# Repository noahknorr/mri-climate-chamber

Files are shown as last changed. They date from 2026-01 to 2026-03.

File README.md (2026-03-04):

# mri-climate-chamber
This is the repository for our open-source climate chamber with in-bore extension for plant MRI.
STEP files with the overall design, including the 3d-printed parts, as well as the layout for the custom PCBs can be downloaded and used according to the licence agreements. 
A technical description, Bill of Materials, performance characterization, and some exemplary measurments on plants can be found in the corresponding publication found under: 

(link not yet available)

We hope to lower the entry barrier to functional MR imaging of plants for other researchers.

# Licenses

All software is licensed under the terms of the GPL-3.0 license and may be used, modified, and redistributed freely, provided that the source code and any derivative works are distributed under the same license.

All hardware is licensed under the terms of the CERN-OHL-W v2 license and may be used, modified, and redistribute freely, provided that any distributed modifications remain under the same license and the source documentation is made available.

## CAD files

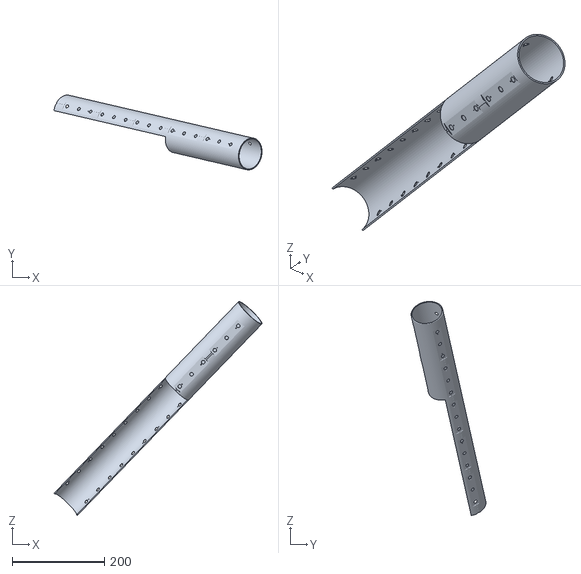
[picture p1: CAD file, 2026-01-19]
3d-files/STLs/einsatz_grundrohr_1.stl
451.2 x 162.3 x 464.4

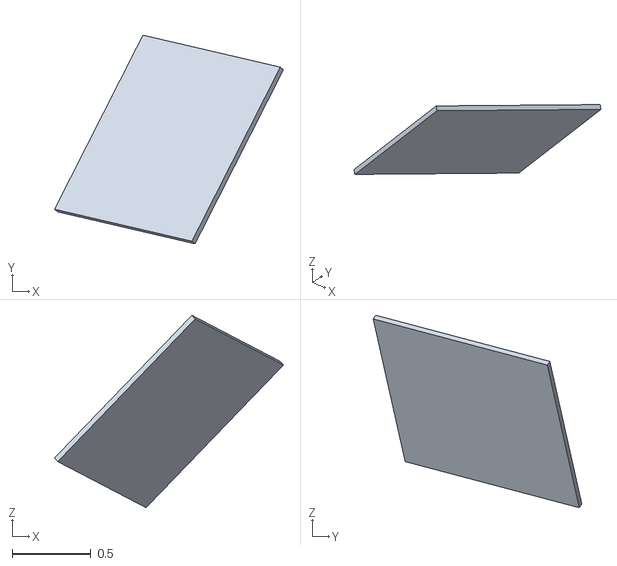
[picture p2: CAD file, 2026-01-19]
3d-files/STLs/einsatz_1_4_6.stl
1.45 x 1.32 x 1.22

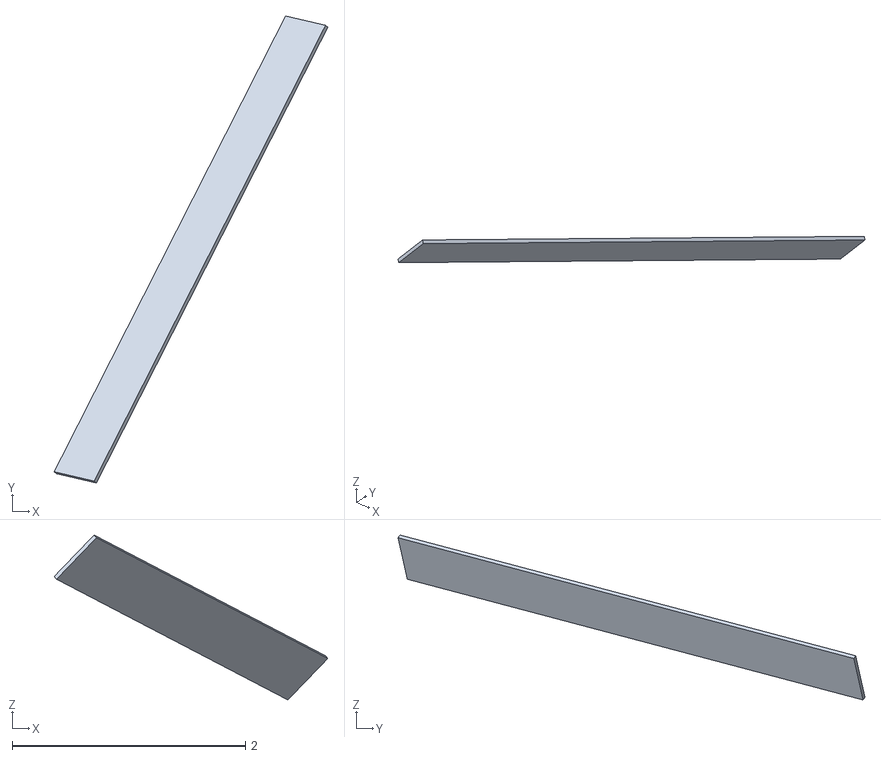
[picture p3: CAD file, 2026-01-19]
3d-files/STLs/einsatz_A_1_13.stl
2.35 x 4.00 x 1.41

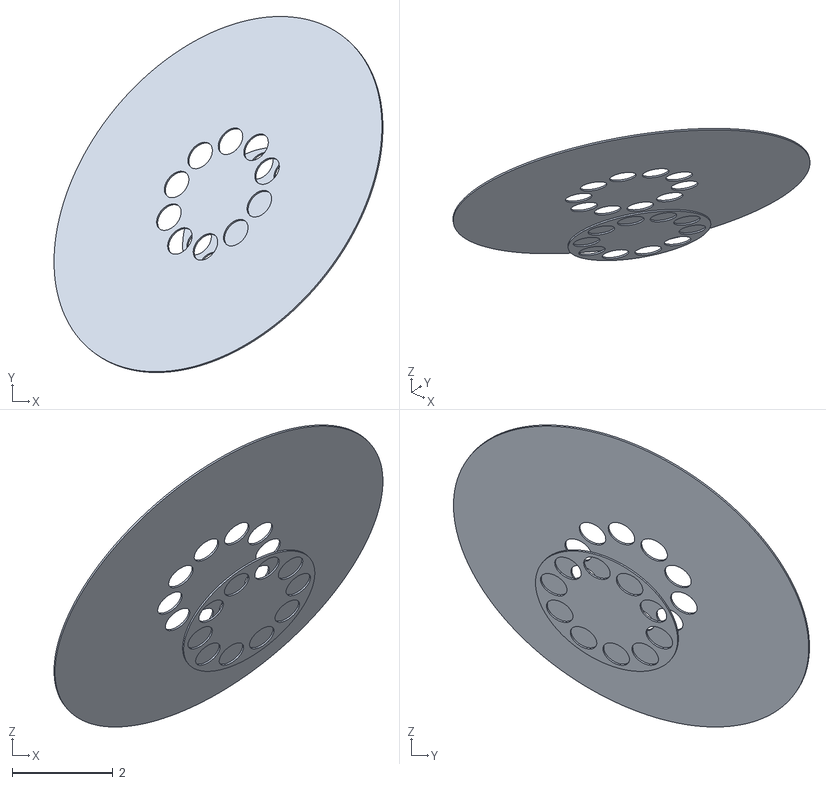
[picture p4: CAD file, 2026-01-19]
3d-files/STLs/einsatz_PIN_1_23.stl
6.53 x 7.07 x 6.00

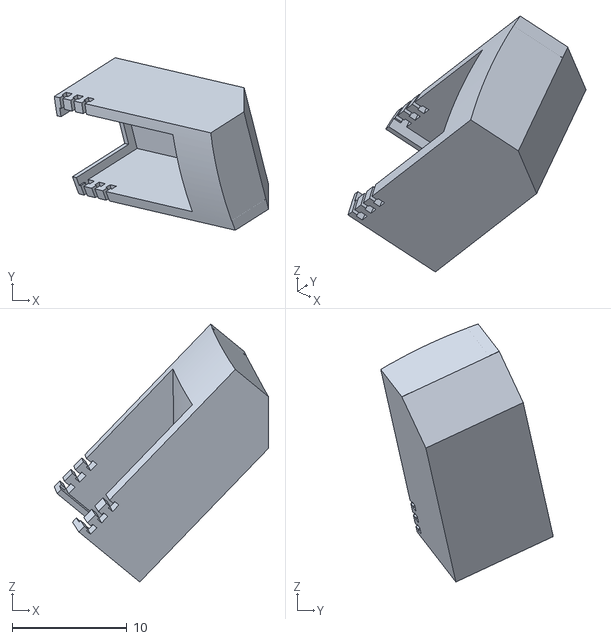
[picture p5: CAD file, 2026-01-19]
3d-files/STLs/einsatz_steckergehaeuseMitAusschnitt_44.stl
18.7 x 15.0 x 22.5

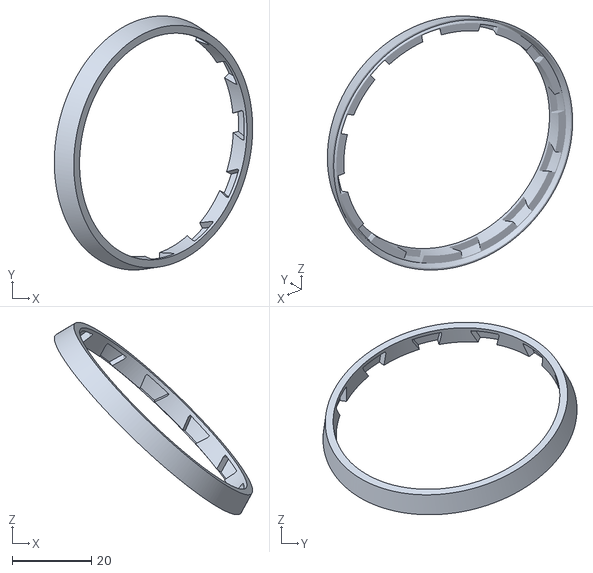
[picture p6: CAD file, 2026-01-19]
3d-files/STLs/einsatz_aufsatzStatorGummi_52.stl
50.1 x 64.2 x 48.6

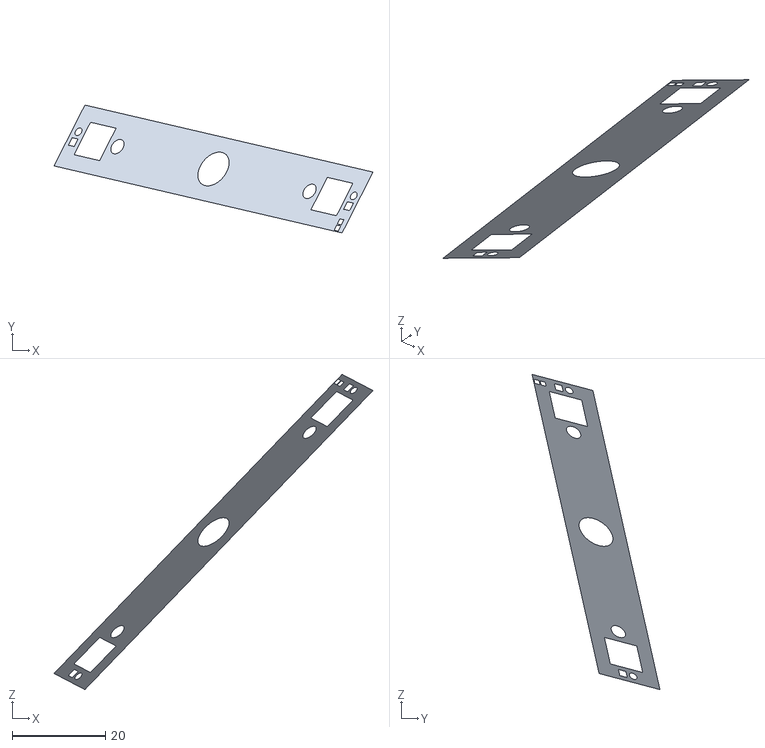
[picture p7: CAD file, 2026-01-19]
3d-files/STLs/einsatz_SOLDERMASK_BOTTOM_34.stl
68.3 x 27.4 x 67.4

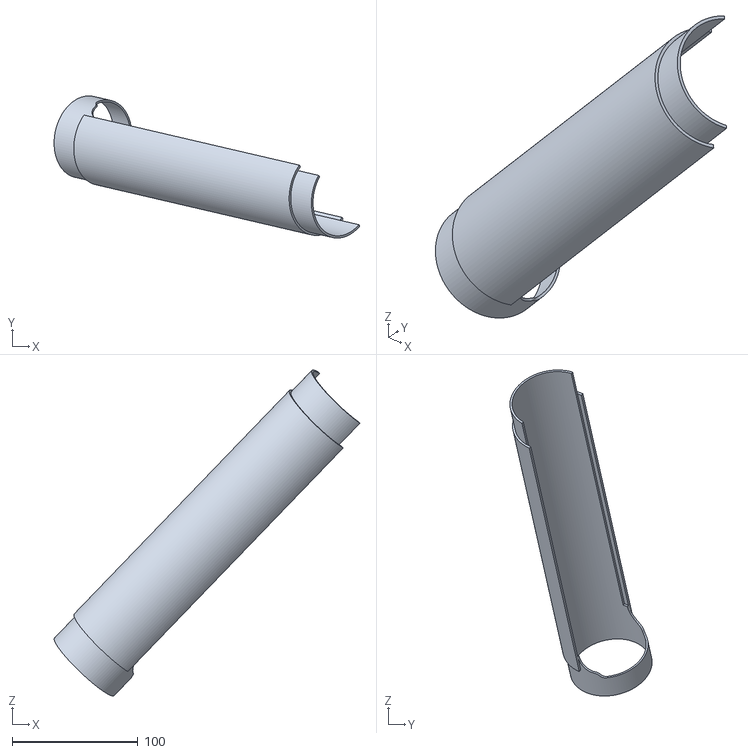
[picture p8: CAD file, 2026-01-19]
3d-files/STLs/einsatz_gegeneinsatz_56.stl
243.1 x 113.0 x 259.2

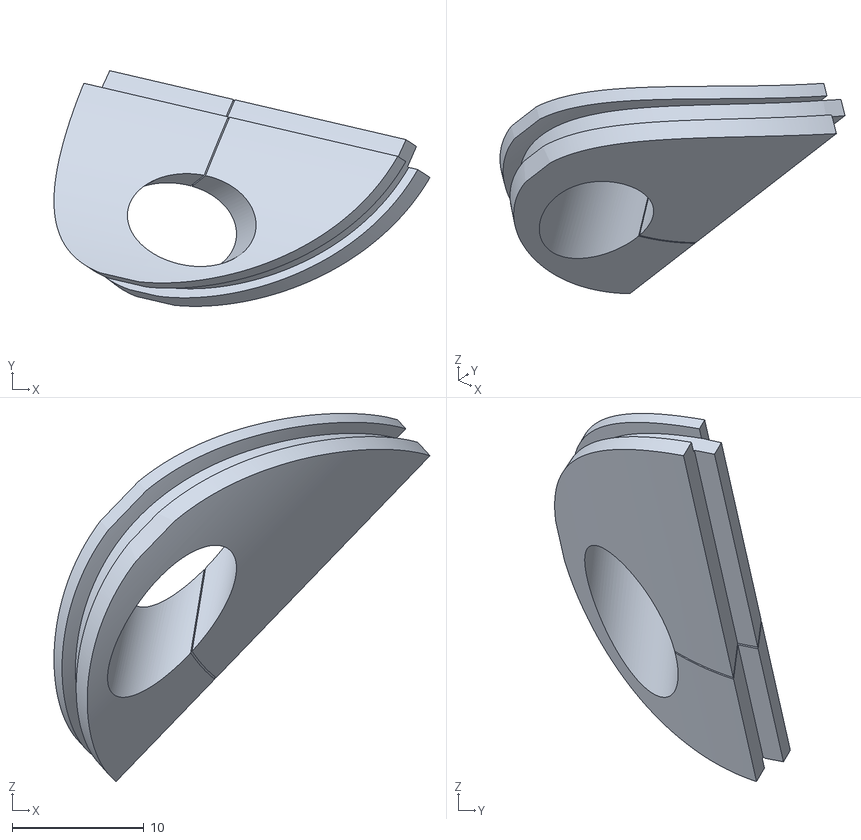
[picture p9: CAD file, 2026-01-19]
3d-files/STLs/einsatz_kappeU5mm_55.stl
28.6 x 17.9 x 28.0

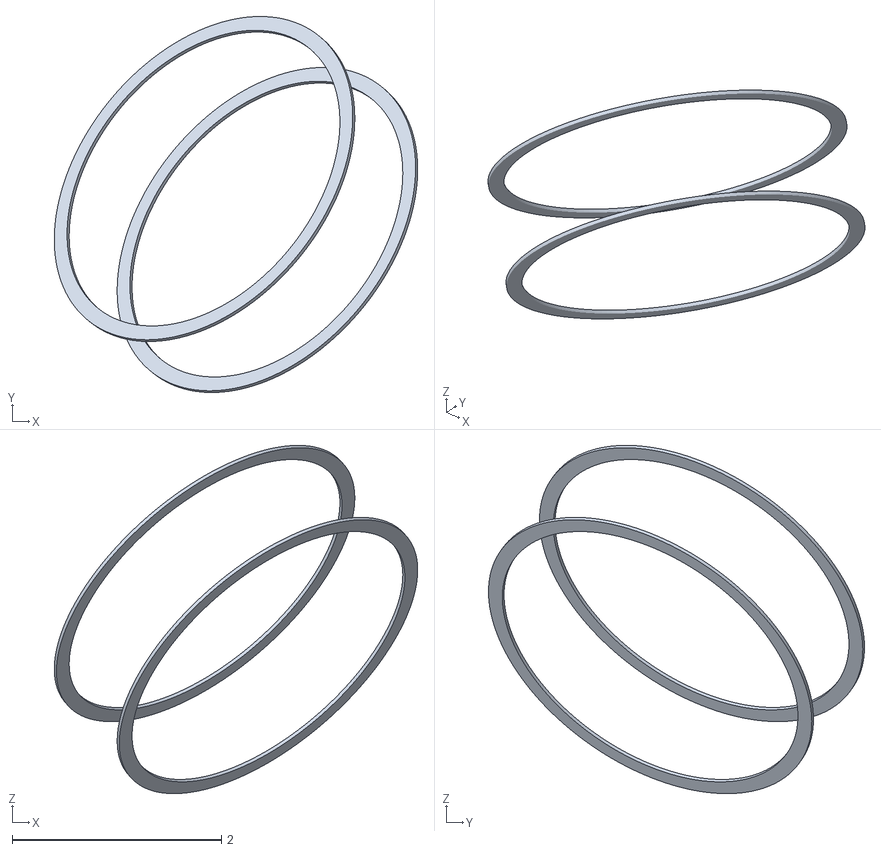
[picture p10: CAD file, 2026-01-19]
3d-files/STLs/einsatz_MECHANICAL PIN_20.stl
3.47 x 3.59 x 3.33

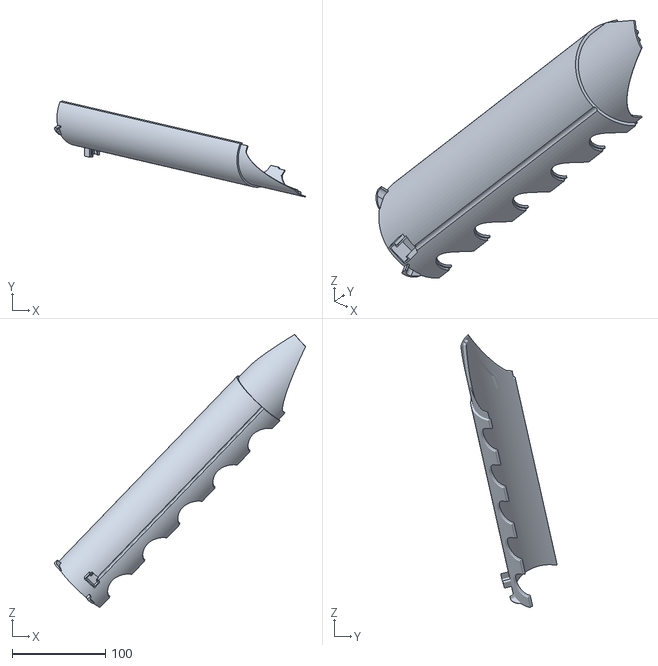
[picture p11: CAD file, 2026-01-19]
3d-files/STLs/einsatz_einsatzU_49.stl
269.7 x 103.3 x 293.1

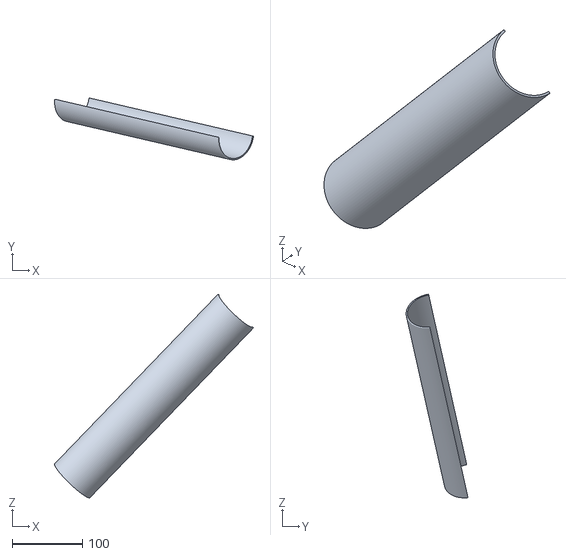
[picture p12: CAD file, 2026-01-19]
3d-files/STLs/einsatz_deckel_43.stl
284.2 x 88.2 x 291.0

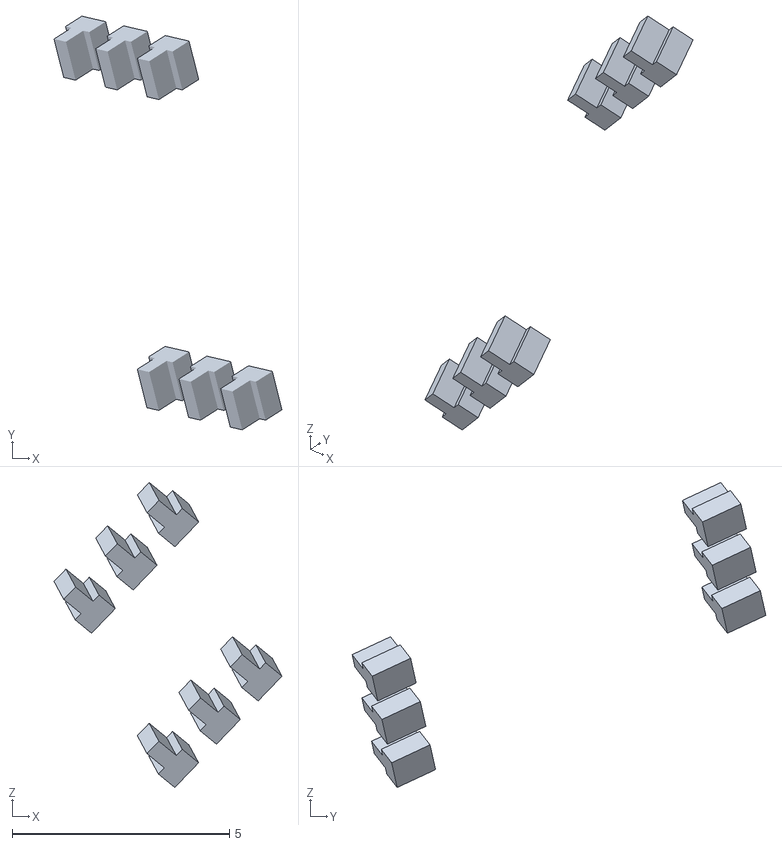
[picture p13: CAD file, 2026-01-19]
3d-files/STLs/einsatz_verbinderGrundrohrLaschen_45.stl
5.24 x 9.52 x 7.02

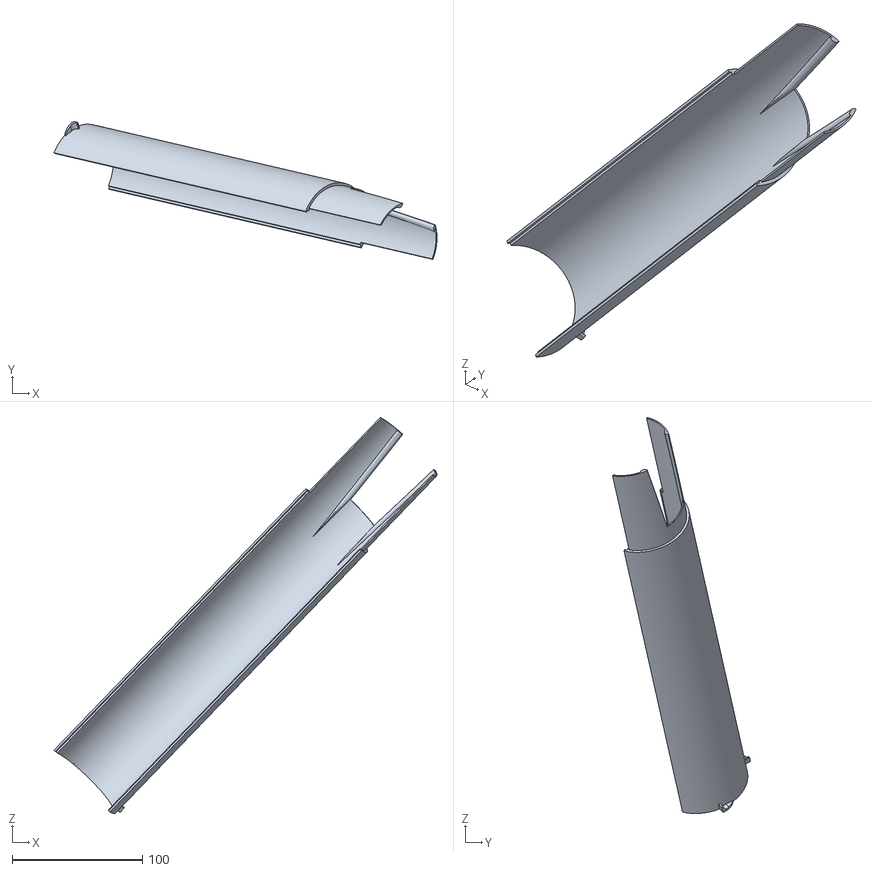
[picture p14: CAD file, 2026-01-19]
3d-files/STLs/einsatz_einsatzO_50.stl
294.1 x 105.9 x 304.2

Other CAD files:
3d-files/STLs/einsatz_steckergehaeuseMitAusschnitt_46.stl
3d-files/STLs/einsatz_MECHANICAL PIN_1_21.stl
3d-files/STLs/schlauchverbinderSchnellverschluss_verbinderHochflexibel-PVC_6.stl
3d-files/STLs/einsatz_SILKSCREEN_BOTTOM_36.stl
3d-files/STLs/einsatz_1_1_3.stl
3d-files/STLs/einsatz_1_2.stl
3d-files/STLs/einsatz_1_2_4.stl
3d-files/STLs/einsatz_1_3_5.stl
3d-files/STLs/einsatz_2_1_8.stl
3d-files/STLs/einsatz_2_2_9.stl
3d-files/STLs/einsatz_2_3_10.stl
3d-files/STLs/einsatz_2_4_11.stl
3d-files/STLs/einsatz_2_7.stl
3d-files/STLs/einsatz_A1_14.stl
3d-files/STLs/einsatz_A2_15.stl
3d-files/STLs/einsatz_A_12.stl
3d-files/STLs/einsatz_BOTTOM_33.stl
3d-files/STLs/einsatz_Dielectric_32.stl
3d-files/STLs/einsatz_HL2X_1_38.stl
3d-files/STLs/einsatz_HL2X_37.stl
3d-files/STLs/einsatz_K1_18.stl
3d-files/STLs/einsatz_K2_19.stl
3d-files/STLs/einsatz_K_16.stl
3d-files/STLs/einsatz_K_1_17.stl
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

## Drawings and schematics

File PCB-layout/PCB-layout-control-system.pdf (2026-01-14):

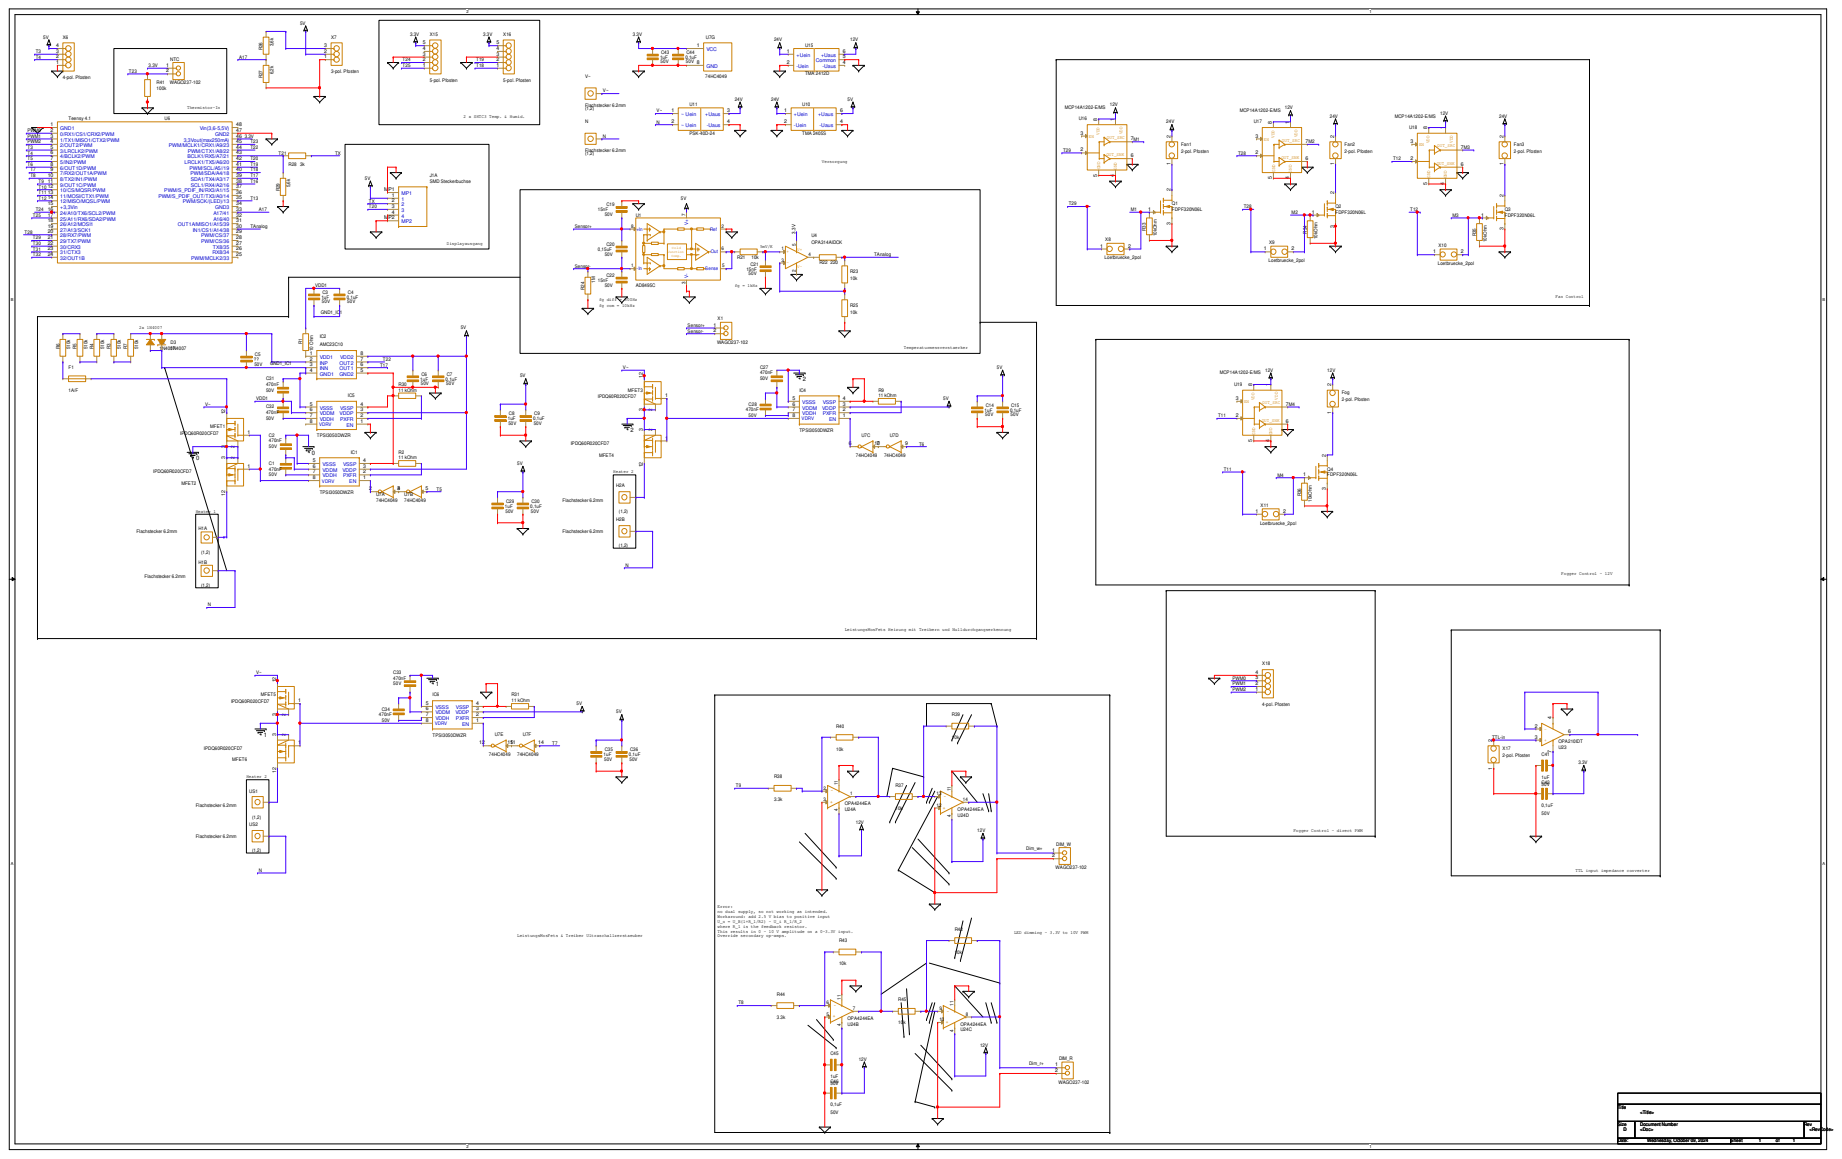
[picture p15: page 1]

LeistungsMosFets Heizung mit Treibern und Nulldurchgangserkennung

Fogger Control - direct PWM

TTL input impedance converter

Error:
no dual supply, so not working as intended.
Workaround: add 2.5 V bias to positive input
where R_1 is the feedback resistor.
This results in 0 - 10 V amplitude on a 0-3.3V input.
Override secondary op-amps.

LED dimming - 3.3V to 10V PWM

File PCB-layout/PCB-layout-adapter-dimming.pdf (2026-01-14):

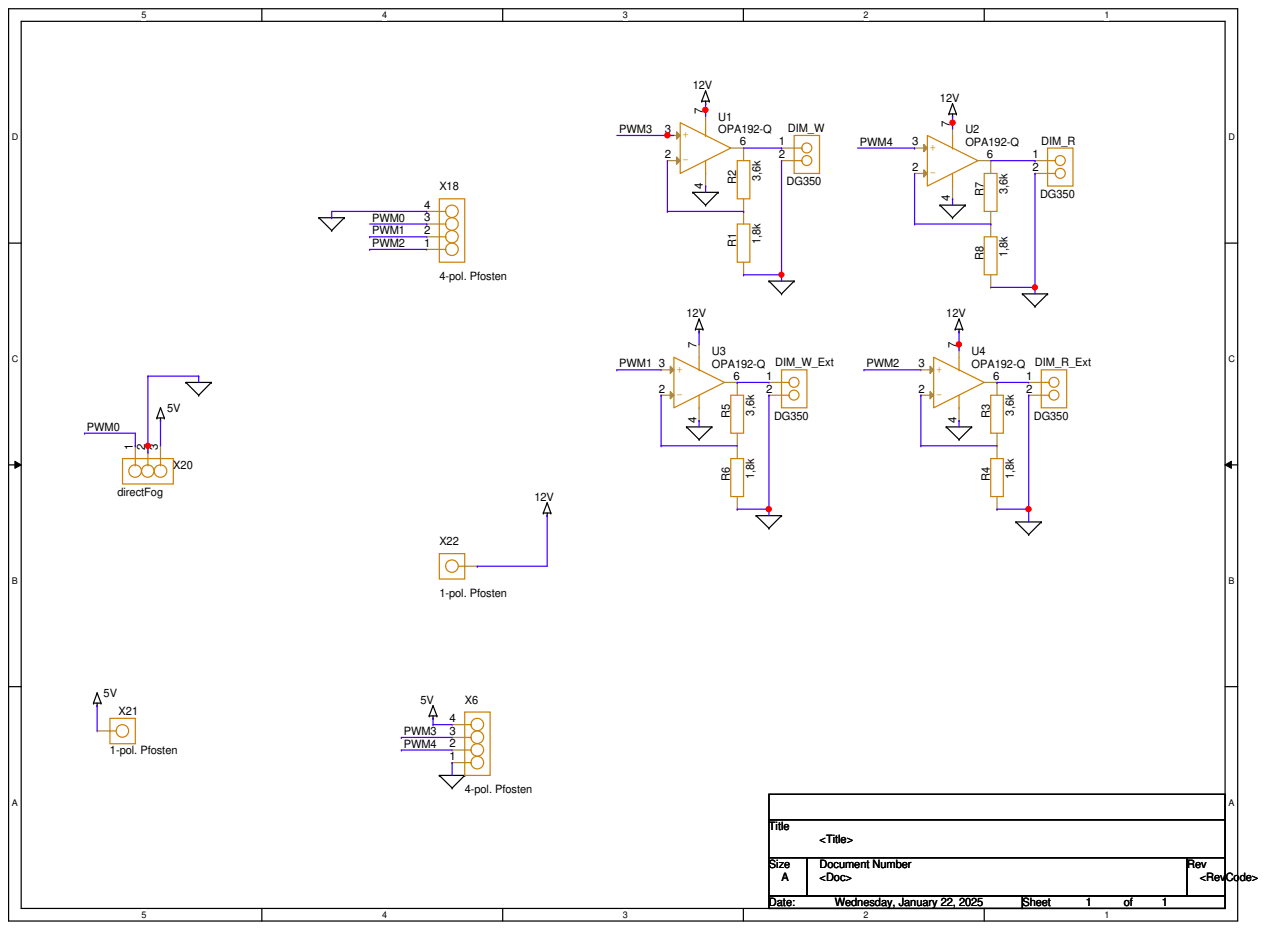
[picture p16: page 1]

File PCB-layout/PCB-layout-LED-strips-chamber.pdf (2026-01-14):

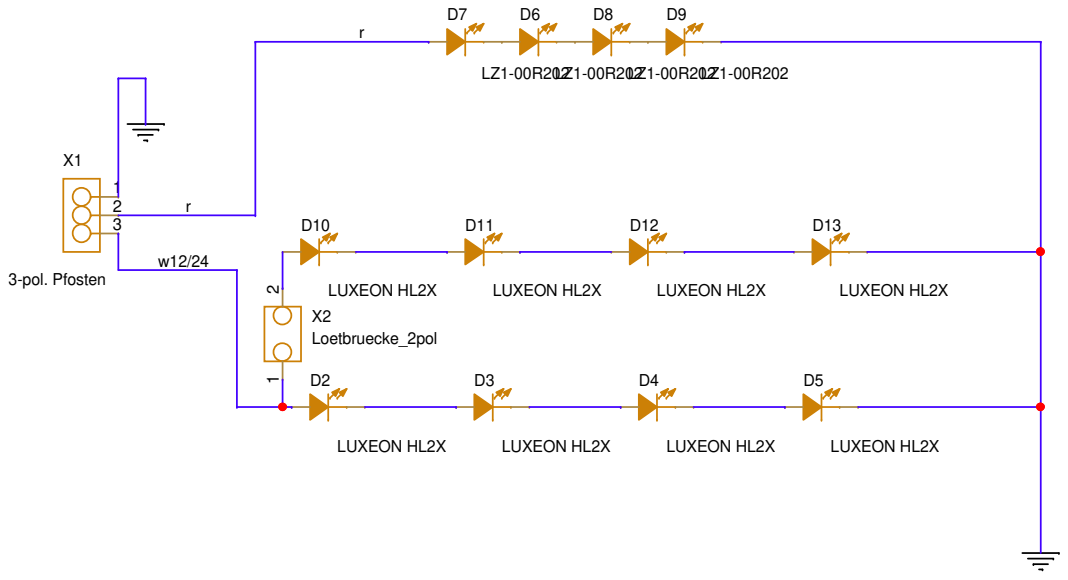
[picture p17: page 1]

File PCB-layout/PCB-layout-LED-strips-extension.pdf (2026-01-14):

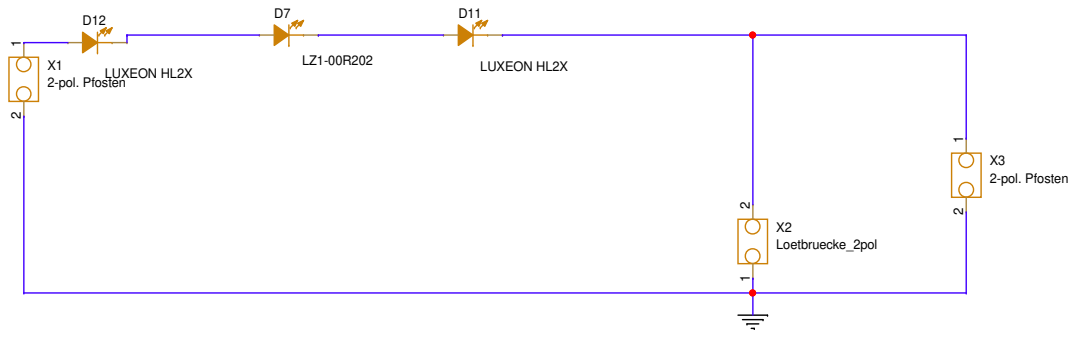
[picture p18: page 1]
Title; Size; Document Number; Rev; Date:; Sheet; <Doc>; <RevCode>; <Title>; 1 1Wednesday, November 13, 2024; X2 Loetbruecke_2pol; LUXEON HL2X; X3 2-pol. Pfosten; X1 2-pol. Pfosten

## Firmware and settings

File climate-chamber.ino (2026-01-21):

#include <EEPROM.h>
#include <Wire.h>
#include "Adafruit_SHTC3.h"
#include <ArtronShop_SHT45.h>
#include <PID_v1.h>
#include <TimeLib.h>
#include <TimeAlarms.h>
#include <arduino-timer.h>
// #include "temperatureRegulator"
#define Nextion Serial5
#define TIME_HEADER  "T"   // Header tag for serial time sync message

float tempTargetValue = 25, humidityTargetValue = 40;
// AlarmId morning;
// AlarmId evening;

double T_heatingPad = 30.0,  outputHeatingPad = 0.0, setpointHeatingPad = 600;
double T_Air = 20, humidityAir = 50, outputAir = 0, outputHumidity = 0, setpointAir = 24, setpointHumidity = 60;
float T_insert = 0, humidityInsert= 0;
double pT = 2, iT = 0.5, dT = 0.001;
double pT_Air = 10, iT_Air = 0.5, dT_Air = 0.005;
double pT_Humidity = 10, iT_Humidity = 0.5, dT_Humidity = 0.005;
bool heating = 1;
bool humidifying = 1;
bool whiteOn = 1;
bool redOn = 1;
bool insertOn = 1;
int maxBrightnessWhite = 102, maxBrightnessRed = 102, maxBrightnessInsert = 255;
int heaterDuty = 0, humidityDuty = 0;
PID heatingMatTempPID(&T_heatingPad, &outputHeatingPad, &setpointHeatingPad, pT, iT, dT, DIRECT);
PID airTempPID(&T_Air, &outputAir, &setpointAir, pT_Air, iT_Air, dT_Air, DIRECT);
PID airHumidityPID(&humidityAir, &outputHumidity, &setpointHumidity, pT_Humidity, iT_Humidity, dT_Humidity, DIRECT);
float humidity_targetValue = 40.0, humidity_actualValue = 0.0;
auto airSensorTimer = timer_create_default();
auto writeValuesToSerialTimer = timer_create_default();

int fan0 = 29;
int fanInsert = 28;
int pwmHumidity = 0;//11;

int dimOutWhite = 3;
int dimOutRed = 4;
int dimOutInsert = 1;
int dimPercentRed = 0, dimPercentWhite = 0, dimPercentInsert = 0;
int dimValueWhite = 2, dimValueRed = 2, dimValueInsert = 2;
int count = 0;
int counterHalfWaves = 0, counterHalfWavesHumidity = 0;
int zeroDetectPin = 22;
int heatingPadTempPin = 23;
float heatingPadTemp = 900;
bool zeroState = 0;
TwoWire *SHTC3_2;
Adafruit_SHTC3 shtc3 = Adafruit_SHTC3();
ArtronShop_SHT45 sht45(&Wire2, 0x44); // SHT45-AD1B => 0x44
int counterDisplayUpdate = 0;

float floatDummy = 25.1;
boolean dummy  = false;
unsigned long timeAlt = 0;

void Nextion_Display_serial_listen() {
  if (Nextion.available() > 0) {
    //Serial.println(Nextion.readString());
    String txtValue = Nextion.readStringUntil(' ');
    String txtIdent = Nextion.readStringUntil(';');
    Serial.print(txtValue.toInt());
    Serial.print(" ... ");
    Serial.println(txtIdent);
        //write setpoints to EEPROM
        //0: temperature integer part & on/off on MSB
        //1: temperature 2 post decimal values (as int)
        //2: humidity integer part & on/off on MSB
        //3: humidity 2 post decimal values (as int)
        //4: dimming white (0 - 100)
        //5: dimming red (0 - 100)
    if(txtIdent=="%"){
      setpointHumidity = txtValue.toFloat();
      if (setpointHumidity < 0) setpointHumidity = 0;
      if (setpointHumidity >100) setpointHumidity = 100;
      Serial.print("Luftfeuchtigkeit  ");
      Serial.print(setpointHumidity);
      Serial.println(txtIdent);
      digitalClockDisplay();
      EEPROM.write(2, (humidifying << 7) ^ int(setpointHumidity));
      EEPROM.write(3,int((setpointHumidity - int(setpointHumidity))*100));
    }
    else if(txtIdent=="W"){
      dimPercentWhite = txtValue.toInt();
      dimValueWhite = map(dimPercentWhite, 0,100,0, maxBrightnessWhite);//10 limits brightness
      // analogWrite(dimOutWhite, dimValueWhite);
      setLedBrightness();
      Serial.print("LED W  ");
      Serial.print(dimPercentWhite);
      Serial.print(" ");
      Serial.println(dimValueWhite);
      EEPROM.write(4,dimPercentWhite ^ (whiteOn << 7));
      Serial.println(dimPercentWhite ^ (whiteOn << 7), BIN);
    }
    else if(txtIdent=="R"){
      dimPercentRed = txtValue.toInt();
      dimValueRed = map(dimPercentRed, 0,100,0, maxBrightnessRed);
      setLedBrightness();
      Serial.print("LED R  ");
      Serial.println(dimValueRed);
      EEPROM.write(5,dimPercentRed ^ (redOn << 7));
    }
    else if(txtIdent=="I"){
      dimPercentInsert = txtValue.toInt();
      dimValueInsert = map(dimPercentInsert, 0,100,0, maxBrightnessInsert);
      setLedBrightness();
      Serial.print("LED I  ");
      Serial.println(dimValueInsert);
      EEPROM.write(6,dimPercentInsert ^ (insertOn << 7));
    }
    else if(txtIdent=="Wt"){
      whiteOn = !whiteOn;
      setLedBrightness();
      // analogWrite(dimOutWhite, 255 - (255 - dimValueWhite) * whiteOn);
      // Serial.print("LED W toggled");
      sendLedStateToNextion();
      EEPROM.write(4,dimPercentWhite ^ (whiteOn << 7));
      // Serial.println(dimPercentWhite ^ (whiteOn << 7), BIN);
    }
    else if(txtIdent=="Rt"){
      redOn = !redOn;
      setLedBrightness();
      // analogWrite(dimOutRed, 255 - (255 - dimValueRed) * redOn);
      sendLedStateToNextion();
      EEPROM.write(5,dimPercentRed ^ (redOn << 7));
    }
    else if(txtIdent=="It"){
      insertOn = !insertOn;
      setLedBrightness();
      digitalWrite(fanInsert, insertOn);
      // analogWrite(dimOutRed, 255 - (255 - dimValueRed) * redOn);
      sendLedStateToNextion();
      EEPROM.write(6,dimPercentInsert ^ (insertOn << 7));
    }
    else if(txtIdent=="h"){
      heating = txtValue.toInt();
      EEPROM.write(0,(heating << 7) ^ int(setpointAir));
      Serial.print("Heater ");
      Serial.println(txtValue);
      heatingMatTempPID.SetMode(heating); //set mode according to heating bool - 0 >> manual mode, 1 >> auto mode
      airTempPID.SetMode(heating);
      setpointHeatingPad = 600; //setpoint low so false heating is less probable
      heaterDuty = 0;
    }    
    else if(txtIdent=="hu"){
      humidifying = txtValue.toInt();
      EEPROM.write(2, (humidifying << 7) ^ int(setpointHumidity));
      Serial.print("Heater ");
      Serial.println(txtValue);
      airHumidityPID.SetMode(humidifying);
      humidityDuty = 0;
    }       
    else{
      if(txtIdent.endsWith("C")){
        setpointAir = txtValue.toFloat();
        if (setpointAir < 20) setpointAir = 20;
        if (setpointAir > 50) setpointAir = 50;
        Serial.print("Temperature  ");
        Serial.print(txtValue);
        Serial.println(" °C"); 
        EEPROM.write(0,(heating << 7) ^ int(setpointAir));
        EEPROM.write(1,int((setpointAir - int(setpointAir))*100));
        // Serial.print(int(setpointAir));
      }
    }
  }
}
bool writeValuesToSerial(void*){
  Serial.print("Set_Air: ");
  Serial.print(setpointAir);
  Serial.print(", T_Air: ");
  Serial.print(T_Air);
  Serial.print(", Set_Hum: ");
  Serial.print(setpointHumidity);
  Serial.print(", humidity: ");
  Serial.print(humidityAir);
  Serial.print(", T_Ins: ");
  Serial.print(T_insert);
  Serial.print(", Hum_Ins: ");
  Serial.print(humidityInsert);
  Serial.print(", Bright_R: ");
  Serial.print(dimPercentRed * redOn);
  Serial.print(", Bright_W: ");
  Serial.print(dimPercentWhite * whiteOn);
  Serial.print(", Bright_I: ");
  Serial.println(dimPercentInsert * insertOn);
  return true;
}
bool getAirData(void *){
  sensors_event_t humidity, temp;
  shtc3.getEvent(&humidity, &temp);  // populate temp and humidity objects with fresh data
  if(sht45.measure()){
    T_insert = sht45.temperature();
    humidityInsert = sht45.humidity();
  }
  T_Air = temp.temperature;
  humidityAir = humidity.relative_humidity;
  writeTemperatureToNextion(float(T_Air));
  writeHumidityToNextion(float(humidityAir));
  writeTemperatureInsertToNextion(float(T_insert));
  writeHumidityInsertToNextion(float(humidityInsert));
  return true;
}
void airRegulator(){
  if(airTempPID.Compute()){
    //Serial.println(humidityAir);
    setpointHeatingPad = map(outputAir, 0, 255, 550, 1000);
  }
  if(heatingMatTempPID.Compute()){
    T_heatingPad= analogRead(heatingPadTempPin);
    heatingPadTemp =  (heatingPadTemp * 99 + analogRead(heatingPadTempPin)) / 100;
    heaterDuty = map( outputHeatingPad, 0, 255, 0, 100);
    counterHalfWaves = 0;
  }
  if (airHumidityPID.Compute()){
    // Serial.print(" humidifying: ");
    // Serial.println(humidifying);
    // Serial.print(" humidityDuty: ");
    // Serial.println(humidityDuty);
    counterHalfWavesHumidity = 0;
    humidityDuty = map(outputHumidity, 0, 255, 0, 1000);
  }
}
void printRegulators(){
  Serial.print("T_Air: ");
  Serial.print(T_Air);
  Serial.print(", setpointAir: ");
  Serial.print(setpointAir);
  Serial.print(", outputAir: ");
  Serial.print(outputAir);
  Serial.print(", T_heatingPad:");
  Serial.print(T_heatingPad);
  Serial.print(",  outputHeatingPad:");
  Serial.print( outputHeatingPad);
  Serial.print(", setpointHeatingPad:");
  Serial.print(setpointHeatingPad);
  Serial.print(", humidity:");
  Serial.print(humidityAir);
  Serial.print(",  outputHumidity");
  Serial.print( outputHumidity);
  Serial.print(", setpointHumidity:");
  Serial.println(setpointHumidity);
}

void writeTemperatureToNextion(float  temperature) {
  String str = "mainPage.tActualTemp.txt=\"" ;
  str += temperature;
  str +=" \xBA C\""; // ° - Zeichen character Encoding iso-8859-1
  commandToNextion(str);
}
void writeHumidityToNextion(float  humidity) {
  String str =  "mainPage.tActualHumi.txt=\"" ;
  str += humidity;
  str += " %\"";
  commandToNextion(str);
}
void writeTemperatureInsertToNextion(float  temperature) {
  String str = "mainPage.T_Insert.txt=\"" ;
  str += temperature;
  str +=" \xBA C\""; // ° - Zeichen character Encoding iso-8859-1
  commandToNextion(str);
}
void writeHumidityInsertToNextion(float  humidity) {
  String str =  "mainPage.humidityInsert.txt=\"" ;
  str += humidity;
  str += " %\"";
  commandToNextion(str);
}
void writeTemperatureSetpointToNextion() {
  String str = "mainPage.tTargetTemp.txt=\"" ;
  str += setpointAir;
  str +=" \xBA C\""; // ° - Zeichen character Encoding iso-8859-1
  commandToNextion(str);
}
void writeHumiditySetpointToNextion() {
  String str =  "mainPage.tTargetHumi.txt=\"" ;
  str += setpointHumidity;
  str += " %\"";
  commandToNextion(str);
}
void writeAirSwitchesToNextion(){
  String str =  "mainPage.switchHeater.val=" ;
  str += heating;
  commandToNextion(str);
  str =  "mainPage.swHumidifier.val=" ;
  str += humidifying;
  commandToNextion(str);
}
void writeWhiteBrightnessToNextion() {
  String str =  "mainPage.dimWhite.val=" ;
  str += dimPercentWhite;
  commandToNextion(str);
}
void writeRedBrightnessToNextion() {
  String str =  "mainPage.dimRed.val=" ;
  str += dimPercentRed;
  commandToNextion(str);
}
void writeInsertBrightnessToNextion() {
  String str =  "mainPage.dimInsert.val=" ;
  str += dimPercentInsert;
  commandToNextion(str);
}
void whiteStateToNextion(){
  String str =  "mainPage.toggleWhite.val=" ;
  str += whiteOn;
  commandToNextion(str);
}
void redStateToNextion(){
  String str =  "mainPage.toggleRed.val=" ;
  str += redOn;
  commandToNextion(str);
}
void insertStateToNextion(){
  String str =  "mainPage.toggleInsert.val=" ;
  str += insertOn;
  commandToNextion(str);
}
void sendLedStateToNextion(){
  String str =  "mainPage.toggleWhite.val=" ;
  str += whiteOn;
  commandToNextion(str);
  str =  "mainPage.toggleRed.val=" ;
  str += redOn;
  commandToNextion(str);
  str =  "mainPage.toggleInsert.val=" ;
  str += insertOn;
  commandToNextion(str);
}
void commandToNextion(String str){
  Nextion.print(str);
  Nextion.print("\xFF\xFF\xFF");
}

void countHalfWaves(){
  counterHalfWaves +=1;
  counterHalfWavesHumidity +=1;

  if (counterHalfWaves < heaterDuty){
    digitalWrite(5, HIGH);
  }
  else{
    digitalWrite(5, LOW);
  }
  if (counterHalfWavesHumidity < humidityDuty){
    analogWrite(pwmHumidity, 128);
  }
  else{
    analogWrite(pwmHumidity, 0);
  }
}
void setLedBrightness(){
  analogWrite(dimOutRed, dimValueRed * redOn); // invert and set value depending on ON/OFF state
  analogWrite(dimOutWhite, dimValueWhite * whiteOn);
  analogWrite(dimOutInsert, dimValueInsert * insertOn);
}

void setup() {
  pinMode(fan0, OUTPUT);
  pinMode(fanInsert, OUTPUT);
  pinMode(pwmHumidity, OUTPUT);
  pinMode(dimOutRed, OUTPUT);
  pinMode(dimOutWhite, OUTPUT);
  pinMode(dimOutInsert, OUTPUT);
  analogWrite(dimOutWhite, 0); // set to "off" (inverted PWM, 255) before reading the stored values later
  analogWrite(dimOutRed, 0);
  analogWrite(dimOutInsert, 0);
  
  Serial.begin(9600);
  Nextion.begin(115200);
  
  pinMode(zeroDetectPin, INPUT);
  analogWriteFrequency(pwmHumidity, 104000);
  analogWriteResolution(8);
  
  analogWriteFrequency(dimOutWhite, 100);//min frequency defined by led driver datasheet, used due to low speed op-amp
  analogWriteFrequency(dimOutRed, 100);
  analogWriteFrequency(dimOutInsert, 100);
  analogWrite(fan0, 175);

  //analogWrite(fan0, 220);
  // analogWrite(pwmHumidity, 128);
//  Serial.begin(115200);

 
  airSensorTimer.every(1000, getAirData);
  writeValuesToSerialTimer.every(10000, writeValuesToSerial);

  Serial.println("SHTC3 test");
  if (!shtc3.begin()) Serial.println("Couldn't find SHTC3");
  else Serial.println("Found SHTC3 sensor");
  Wire2.begin();
  if (!sht45.begin()) {
    Serial.println("SHT45 not found !");
    delay(1000);
  }
  attachInterrupt(22, countHalfWaves, CHANGE);

  //Read setpoints from EEPROM
  //0: temperature integer part & heating bool as MSB
  //1: temperature 2 post decimal values (as int)
  //2: humidity integer part & humidifying bool as MSB
  //3: humidity 2 post decimal values (as int)
  //4: dimming white (0 - 100) and on/off as MSB
  //5: dimming red (0 - 100) and on/off as MSB
  setpointAir = float(EEPROM.read(0) & ~(1 << 7))  + float(~(1<<7) & EEPROM.read(1))/100;
  setpointHumidity = float(EEPROM.read(2) & ~(1 << 7)) + float(EEPROM.read(3))/100;
  heating = EEPROM.read(0) & (1 << 7);
  humidifying = EEPROM.read(2) & (1 << 7);
  dimPercentWhite = ~(1<<7) & EEPROM.read(4);
  dimPercentRed = ~(1<<7) & EEPROM.read(5);
  dimPercentInsert = ~(1<<7) & EEPROM.read(6);
  whiteOn = (1<<7) & EEPROM.read(4);
  redOn = (1<<7) & EEPROM.read(5);
  insertOn = (1<<7) & EEPROM.read(6);
  dimValueWhite = map(dimPercentWhite, 0,100,0, maxBrightnessWhite);
  dimValueRed = map(dimPercentRed, 0,100,0, maxBrightnessRed);
  dimValueInsert = map(dimPercentInsert, 0,100,0, maxBrightnessInsert);
  setLedBrightness();
  digitalWrite(fanInsert, insertOn);

  heatingMatTempPID.SetMode(heating);
  heatingMatTempPID.SetSampleTime(1000);
  airTempPID.SetMode(heating);
  airTempPID.SetSampleTime(1000);
  airHumidityPID.SetMode(humidifying);
  airHumidityPID.SetSampleTime(10000);

  // analogWrite(dimOutRed, 255 - (255 - dimValueRed) * redOn); // invert and switch to value depending on 
  // analogWrite(dimOutWhite, 255 - (255 - dimValueWhite) * whiteOn);
  delay(1500);
  //write EEPROM stored values to display
  writeAirSwitchesToNextion();
  writeTemperatureSetpointToNextion();
  writeHumiditySetpointToNextion();
  writeWhiteBrightnessToNextion();
  writeRedBrightnessToNextion();
  writeInsertBrightnessToNextion();
  whiteStateToNextion();
  redStateToNextion();
  insertStateToNextion();
  setSyncProvider(getTeensy3Time);
  Alarm.alarmRepeat(8,0,0, boxLightsOn);
  Alarm.alarmRepeat(18,0,0, boxLightsOff);
  // setSyncProvider(getTeensy3Time);
  digitalClockDisplay();
  Serial.println("finished setup...");
}
void loop() {
    if (Serial.available()) {
    time_t t = processSyncMessage();
    if (t != 0) {
      Teensy3Clock.set(t); // set the RTC
      setTime(t);
    }
  }
  Nextion_Display_serial_listen();
  airSensorTimer.tick();
  writeValuesToSerialTimer.tick();

  airRegulator();
  //  digitalClockDisplay();
   Alarm.delay(0); // wait one second between clock display

}

void boxLightsOff(){
  Serial.println("lights off");
  redOn = 0;
  whiteOn = 0;
  setLedBrightness();
  whiteStateToNextion();
  redStateToNextion();
}
void boxLightsOn(){
  Serial.println("lights on");
  redOn = 1;
  whiteOn = 1;
  setLedBrightness();
  whiteStateToNextion();
  redStateToNextion();
}
time_t getTeensy3Time()
{
  return Teensy3Clock.get();
}
unsigned long processSyncMessage() {
  unsigned long pctime = 0L;
  const unsigned long DEFAULT_TIME = 1357041600; // Jan 1 2013 

  if(Serial.find(TIME_HEADER)) {
     pctime = Serial.parseInt();
     return pctime;
     if( pctime < DEFAULT_TIME) { // check the value is a valid time (greater than Jan 1 2013)
       pctime = 0L; // return 0 to indicate that the time is not valid
     }
  }
  return pctime;
}
void printDigits(int digits){
  // utility function for digital clock display: prints preceding colon and leading 0
  Serial.print(":");
  if(digits < 10)
    Serial.print('0');
  Serial.print(digits);
}
void digitalClockDisplay() {
  // digital clock display of the time
  Serial.print(hour());
  printDigits(minute());
  printDigits(second());
  Serial.print(" ");
  Serial.print(day());
  Serial.print(" ");
  Serial.print(month());
  Serial.print(" ");
  Serial.print(year()); 
  Serial.println(); 
}

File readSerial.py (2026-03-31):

import serial
import csv
import time
import datetime

# Setup
ser = serial.Serial(port='COM3', baudrate=9600, timeout=1)
print(datetime.date.today().year)
output_file = "recording_" + str(datetime.datetime.now().year) + f'{datetime.datetime.now().month:02}'+ f'{datetime.datetime.now().day:02}' + "_" + f'{datetime.datetime.now().hour:02}' + f'{datetime.datetime.now().minute:02}' + ".csv"
print(output_file)
# Read and write
with open(output_file, mode='w', newline='\n') as file:
    file.write("sep=,\n")
    writer = None  # CSV writer will be defined after headers are known
    try:
        print(f"Reading from {ser.port} and writing to {output_file}, press Ctrl C to end recording...")
        while True:
            if ser.in_waiting:
                line = ser.readline().decode('utf-8').strip()
                # Example format: "Temp=25.3 Humidity=60.1"
                parts = line.split(',')
                data = {}
                data['unixSeconds'] = time.time()
                for part in parts:
                    key, value = part.split(':')
                    if ':' in part:
                        data[key.strip()] =  float(value.strip())
                # Initialize writer and write header
                if writer is None:
                    writer = csv.DictWriter(file, fieldnames=list(data.keys()))
                    writer.writeheader()
                #print("line written")
                print(data)
                writer.writerow(data)
                file.flush()
    except KeyboardInterrupt:
        print("Stopped by user.")
    finally:
        ser.close()

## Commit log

2026-01-08 stp. file of the main acrylic chamber
2026-01-21 Update and rename Klimakammer.ino to climate-chamber.ino
